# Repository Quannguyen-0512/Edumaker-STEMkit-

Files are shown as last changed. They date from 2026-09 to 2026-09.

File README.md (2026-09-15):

# EduMaker STEMKit

**Award:** 3rd Prize, SV.STARTUP national entrepreneurship competition.

**Role:** Specified the board requirements (ESP32 S3, labeled sensor ports) and had a manufacturer turn that into an actual PCB. Milled the board on a desktop CNC with my teacher's help, since I wasn't experienced with that process myself. Designed and 3D printed the casing myself. Wrote the code and designed both sample projects (the remote control car and the smart home). Built and trained the companion chatbot myself.

I built EduMaker STEMKit to help students learn programming and robotics through hands-on building instead of just theory. Instead of one fixed circuit, I designed it as a set of snap together blocks (sensor, controller, display, AI unit) that combine into different builds. I also built two sample projects, a remote control car and a smart home, so students have ready-made projects to learn from.

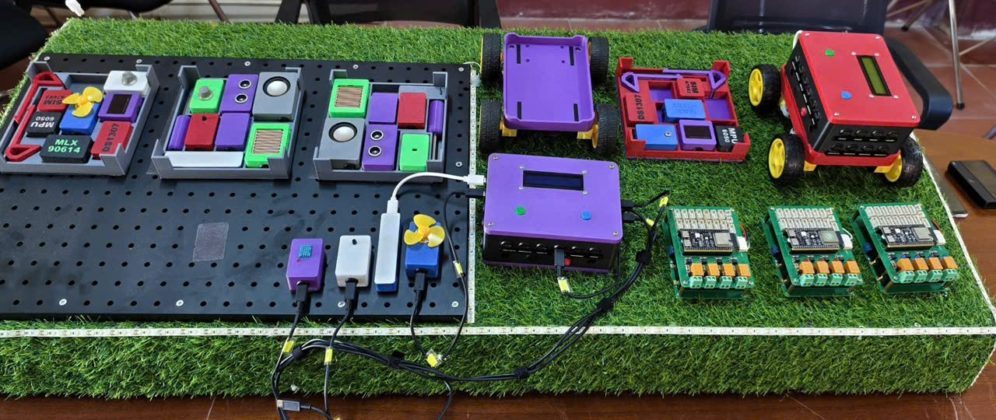
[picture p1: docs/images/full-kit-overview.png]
Full kit overview


## What it is

I made two versions for two different stages of learning:

| Version | What it looks like | Who it's for |
|---|---|---|
| **Starter** | Bare board, wires exposed | Students still learning the hardware itself: wiring, pin layout, raw code |
| **Comfort** | Same board, 3D printed case | Students who already know the hardware and want to focus on the software |

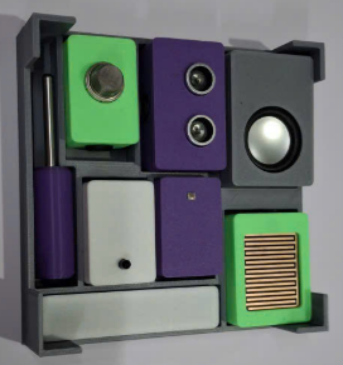
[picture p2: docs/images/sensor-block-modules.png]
Sensor block modules

*What the sensor blocks look like taken apart*

## Hardware

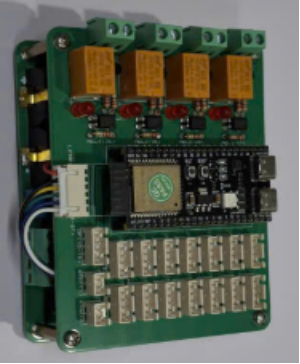
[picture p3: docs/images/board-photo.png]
Board close-up


| Component | Function |
|---|---|
| ESP32 S3 | Main controller (center of the board) |
| DHT11 | Temperature and humidity |
| MLX90614 | Infrared (contactless) temperature |
| Heart rate sensor | Pulse sensing |
| MPU6050 | Accelerometer / gyroscope |
| RTC module | Real time clock |
| Analog sensor port | General purpose analog input |
| RGB LED | Status/color feedback |
| OLED / LCD | Text and graphic display |
| Bluetooth module | Short range wireless control |
| SIM/GSM module | Cellular connectivity |

I couldn't lay out the circuit board myself, so I specified what it needed (an ESP32 S3 at the center, labeled ports for sensors like gas, fire, and heart rate) and a manufacturer turned that into the actual board above.

Full pin mapping for every port on the board: [`docs/pin-mapping.md`](docs/pin-mapping.md).

## Projects

### Remote control car

Controlled over Bluetooth from the companion Android app (see Mobile app below). The app sends single character commands (`G` forward, `B` back, `L` left, `R` right, `S` stop) over a serial connection, and the board turns those into motor signals through the L298 driver.

Code: [`remote-control-car.ino`](firmware/projects/remote-control-car/remote-control-car.ino), [`functions.ino`](firmware/projects/remote-control-car/functions.ino)

### Smart home

Built on Blynk, so it can be monitored and controlled remotely through the Blynk app instead of only from a local switch. Reads gas and fire sensors, a DHT11 for temperature/humidity, and shows readings on an LCD. Controls a lamp and a fan, and sounds a buzzer if it detects gas or fire.

Code: [`smart-home.ino`](firmware/projects/smart-home/smart-home.ino)

## AI Chatbot

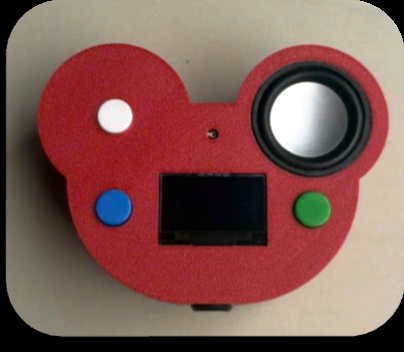
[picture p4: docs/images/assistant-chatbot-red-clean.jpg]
Chatbot device


A board like Arduino has years of forum threads to fall back on when something breaks. A brand new kit has none of that, so I built a chatbot to cover that gap myself.

* I built it on an existing AI model (through the Xiaozhi AI platform, running DeepSeek V4) rather than training one from scratch.
* I trained it on data specific to this board (every port, every pin, what each one is normally used for) so it can actually help with *this* kit instead of answering generic embedded systems questions. The full reference data is in [`docs/pin-mapping.md`](docs/pin-mapping.md).
* It's tuned to understand users speaking in a Mekong Delta / Southern Vietnamese accent, since that's who the kit is built for.
* It runs as a voice assistant, so a student can just ask it something out loud.
## Presentation 
Video context: EduMaker STEM Kit introduction

This clip is a short excerpt from a longer competition pitch presentation (SV STARTUP 2026) for the EduMaker STEM Kit.

In this segment, I introduce the kit's two tiers: a Basic version (a bare circuit board with essential sensors, aimed at beginners learning wiring fundamentals) and a more advanced version that abstracts away the wiring so students can focus purely on programming. I also highlight a built-in AI chatbot, trained specifically on the kit's own technical data (modules, pin wiring, usage instructions) to give students 24/7 support.

Watch the video here: 

Watch the video (https://youtu.be/ppT96pnb7yc)

## Repository layout

| Folder | Contents |
|---|---|
| `hardware/pcb/` | Proteus source for the top and bottom boards, plus exported Gerber/drill files (`gerber-export.zip`) ready for manufacturing |
| `hardware/cnc/` | G-code toolpaths (`.tap`) I used to mill the board on a desktop CNC |
| `enclosure/` | SketchUp source for the 3D printed case and sensor mounts |
| `firmware/module-tests/` | One minimal Arduino sketch per module, to confirm a single sensor works before combining it into a build |
| `firmware/projects/` | Integrated builds: the remote control car and the Blynk based smart home |
| `mobile-app/` | Companion Android app for the car (`.aia` source + installable `.apk`) |
| `docs/pin-mapping.md` | Full port/pin reference for the board, also used as the chatbot's training data |

## Getting started

1. Want to test a single module? Open any sketch in `firmware/module-tests/<module-name>/`.
2. Want to see how modules combine into a real build? Look at `firmware/projects/`.
3. Want to fabricate your own board? `hardware/pcb/` has the Proteus source; `gerber-export.zip` in each board folder is ready to send to a manufacturer.
4. Want to print your own case? Case files are in `enclosure/` (SketchUp).

## Future development

I want to keep improving the training data based on real feedback: once the kit is actually in students' hands (especially if it starts selling to more schools), I can see what they actually ask and where they get stuck, and update the prompt from that instead of guessing.

I also want to keep building more sample projects, so students have a wider range of ready-made builds to learn from beyond the car and the smart home.

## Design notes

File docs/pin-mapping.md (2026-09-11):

# EduMaker STEMKit — Pin Mapping Reference

This is the actual reference data used to train the companion chatbot (see [AI Chatbot](../README.md#ai-chatbot) in the main README). It documents every port on the board and what it's wired to.

## Microcontroller

**ESP32-S3 N16R8**, programmed via Arduino IDE. Board setting: `ESP32S3 Dev Module`.

## Port map

| Port group | Pins | Typical use |
|---|---|---|
| L298 motor driver | ENA = 42, IN1 = 41, IN2 = 40, IN3 = 39, IN4 = 38, ENB = 37 | Drives the L298 motor driver |
| Top row, right side (4× Type-C) | SDA = 8, SCL = 9 (shared bus across all 4 ports) | I2C peripherals by default, but usable for other functions if needed |
| Bottom row, right side (4× Type-C) | 14, 13, 12, 11 | Analog peripherals |
| Rear (4× Type-C, paired) | (18, 17), (16, 15), (7, 6) | UART peripherals, one pair per port |
| Rear (2× Type-C) | 5, 4 | One-wire sensors such as DS18B20 and DHT11 |
| Left side (4× Type-C) | 47, 48, 35, 36 | Direct control outputs for lamp/fan models |
| Bottom left (2× Type-C) | Wired to the L298's left/right motor channels | Motor base connector (board mounted vertically) |
| Buzzer | 21 | Onboard alert buzzer |
| Front (2× Type-C) | | Code upload / flashing |
| Onboard | I2C 16x2 LCD; buttons on pin 1 and pin 2 | Built-in display and input |

## Note on accent

The chatbot is trained to expect users speaking in a Mekong Delta / Southern Vietnamese accent, since that's who the kit is built for.

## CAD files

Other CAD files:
enclosure/assistant-box.skp
enclosure/case.skp
enclosure/sensor-mount.skp

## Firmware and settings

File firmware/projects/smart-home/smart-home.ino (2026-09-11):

//edumakerstemkit@gmail.com

//-------------------------------------------------------------------------------------------------------- Blynk
#define BLYNK_PRINT Serial
#include <WiFi.h>
#include <WiFiClient.h>
#include <BlynkSimpleEsp32.h>
//-------------------------------------------------------------------------------------------------------- Màn hình
#include <Wire.h> 
#include <LiquidCrystal_I2C.h>
LiquidCrystal_I2C lcd(0x27,16,2);
//-------------------------------------------------------------------------------------------------------- Cảm biến DHT11
#include "DHT.h"
DHT dht(5, DHT11);
//-------------------------------------------------------------------------------------------------------- Biến toàn cục
unsigned long timer; 
//-------------------------------------------------------------------------------------------------------- Khởi tạo ngoại vi
#define LAMP 47
#define FAN 48
#define GAS 14
#define FIRE 13
#define BUZZE 21

BLYNK_WRITE(V2){ digitalWrite(LAMP, param.asInt()); }
BLYNK_WRITE(V3){ digitalWrite(FAN, param.asInt()); }
void setup() 
{
//-------------------------------------------------------------------------------------------------------- Serial debug
  Serial.begin(9600);
//-------------------------------------------------------------------------------------------------------- Khởi động ngoại vi
  pinMode(LAMP, OUTPUT);
  pinMode(FAN, OUTPUT);
  pinMode(BUZZE, OUTPUT);
  pinMode(GAS, INPUT);
  pinMode(FIRE, INPUT);
//-------------------------------------------------------------------------------------------------------- Khởi động cảm biến nhiệt độ
  dht.begin();
//-------------------------------------------------------------------------------------------------------- Khởi động màn hình
  Wire.begin(8,9);
  lcd.init();                  
  lcd.backlight();
  lcd.setCursor(3,0); lcd.print("Hello, world!");
  delay(1000);
//-------------------------------------------------------------------------------------------------------- Server connecting
  Blynk.begin("gC_iZ2f-ibVtzkzkCQRYFupU5Vda9-jr", "Factory3", "39393939", "kenhsangtaotre.ddns.net", 8080);
  lcd.clear();
}

void loop() 
{
//-------------------------------------------------------------------------------------------------------- Đọc cảm biến
  float h = dht.readHumidity();
  float t = dht.readTemperature();
  if (isnan(h) || isnan(t)) {Serial.println(F("Failed to read from DHT sensor!"));return;}

  int gas_value = analogRead(GAS);
  int fire_value = 4095-analogRead(FIRE);
//-------------------------------------------------------------------------------------------------------- Monitor
  lcd.setCursor(0,0); lcd.print("H:"); lcd.print(h); 
  lcd.setCursor(0,1); lcd.print("T:"); lcd.print(t); 
  lcd.setCursor(9,0); lcd.print("G:"); lcd.print(gas_value); 
  lcd.setCursor(9,1); lcd.print("F:"); lcd.print(fire_value); 
//-------------------------------------------------------------------------------------------------------- Cloud send data
  if(millis()-timer > 500)
  {
    Blynk.virtualWrite(V0, t);
    Blynk.virtualWrite(V1, h);
    Blynk.virtualWrite(V4, gas_value);
    Blynk.virtualWrite(V5, fire_value);
    timer = millis();
  }
//-------------------------------------------------------------------------------------------------------- Detection
  if(gas_value > 2000 || fire_value > 2000)
  {
    digitalWrite(BUZZE,1); delay(50);
    digitalWrite(BUZZE,0); delay(50);
  }
}

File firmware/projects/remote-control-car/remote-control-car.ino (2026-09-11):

#define ENA 37
#define IN1 39
#define IN2 38
#define IN3 40
#define IN4 41
#define ENB 42

void setup() 
{
  Serial.begin(115200);
  Serial2.begin(9600, SERIAL_8N1, 8, 9);

  pinMode(ENA, OUTPUT); digitalWrite(ENA,1);
  pinMode(IN1, OUTPUT);
  pinMode(IN2, OUTPUT);
  pinMode(IN3, OUTPUT);
  pinMode(IN4, OUTPUT);
  pinMode(ENB, OUTPUT); digitalWrite(ENB,1);
}

void loop() 
{
  if (Serial2.available()) 
  {
    char DATA = Serial2.read();


    if(DATA == 'G') {GO();}
    if(DATA == 'B') {BACK();}
    if(DATA == 'L') {LEFT();}
    if(DATA == 'R') {RIGHT();}
    if(DATA == 'S') {STOP();}
  }
}

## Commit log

2026-09-11 Reorganize files into proper folder structure and add missing module tests
    [assistant-box.skp, case.skp, sensor-mount.skp]
2026-09-11 Add missing top-board gerber export
2026-09-12 Update voice assistant description in README
    Removed reference to hunting for a forum thread in voice assistant description.
2026-10-17 Change buzzer pin mapping to pin 21
    Updated buzzer pin mapping from pin 8 to pin 21.
